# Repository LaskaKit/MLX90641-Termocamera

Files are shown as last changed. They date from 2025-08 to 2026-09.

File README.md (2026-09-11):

# Thermal camera module MLX90641 16×12 px, 55°×35° with μSup connector

A compact thermal camera (thermal imaging) module built around the **Melexis MLX90641** far-infrared array sensor. It gives you **192 real temperature readings (16×12 px)** in every frame, at up to 64 Hz, over I²C - no contact, no extra optics, no calibration needed. Point it at a board, a motor, a radiator, a face or a soldering iron tip and you get the temperature of every point in the scene.

Assembled module

Typical uses: overheating detection on PCBs and in electrical cabinets, presence and people counting, heat-loss inspection, 3D printer and machine monitoring, robotics, or just a DIY thermal camera with a display.

## Why this module and not the bare sensor

The MLX90641 alone is a 4-pin TO-39 can that you have to wire, pull up and power yourself. On this module you get:

- the sensor already soldered on a PCB with the correct decoupling,
- a **[μSup connector](https://blog.laskakit.cz/predstavujeme-univerzalni-konektor-pro-propojeni-modulu-a-cidel-%CE%BCsup/)** - plug it into any LaskaKit board with a single 4-wire cable, no soldering at all,
- solder pads for a standard 2.54 mm 4-pin header (straight or right-angle) if you prefer a breadboard,
- mounting holes so you can actually fix the camera where it should look,
- and **working example code** - Arduino firmware plus a Python live heatmap viewer, see [SW](https://github.com/LaskaKit/MLX90641-Termocamera/tree/main/SW).

## Specification

| | |
|---|---|
| Sensor | Melexis MLX90641 |
| Resolution | 16 × 12 px (192 measuring points) |
| Field of view (FOV) | 55° × 35° |
| Temperature range of the scene | -40 °C to +300 °C |
| Refresh rate | up to 64 Hz (0.5 / 1 / 2 / 4 / 8 / 16 / 32 / 64 Hz) |
| Accuracy | typ. ±1 °C (see the Melexis datasheet) |
| Interface | I²C, up to 1 MHz |
| I²C address | **0x33** |
| Supply voltage | 3.3 V |
| Connectors | μSup (JST-SH 1.0 mm, 4-pin) + pads for a 2.54 mm 4-pin header |
| Module dimensions | 22.9 × 21.6 mm |

Bottom side of the module

## How to connect it

The μSup connector carries **3V3, GND, SDA, SCL**. Connect the module to any of our boards with a single cable - for example the [ESP32-S3 DevKit](https://www.laskakit.cz/laskakit-esp32-s3-devkit/), the [ESP32-DEVKit](https://www.laskakit.cz/laskakit-esp32-devkit/), the low-power [ESP32-C3 LPKit](https://www.laskakit.cz/laskkit-esp-12-board/), [Meteo Mini](https://www.laskakit.cz/laskakit-meteo-mini/) or the [ESPD-3.5 with a 3.5" TFT display](https://www.laskakit.cz/laskakit-espd-35-esp32-3-5-tft-ili9488-touch/), for which we have a **ready-made thermal camera application** - see [ESPD-35/SW/MLX90641-Termocamera](https://github.com/LaskaKit/ESPD-35/tree/main/SW/MLX90641-Termocamera).

You are of course not limited to our boards - any [Arduino](https://www.laskakit.cz/arduino-2/), [Raspberry Pi or Rock Pi](https://www.laskakit.cz/mini-pc/) with a 3.3 V I²C bus will do. Just keep in mind the module is **3.3 V only**, so use a level shifter with 5 V boards.

## Example code

Everything you need is in [SW/mlx90641-test](https://github.com/LaskaKit/MLX90641-Termocamera/tree/main/SW/mlx90641-test):

- `mlx90641-test.ino` - Arduino sketch for ESP32 (tested on LaskaKit ESP32-S3 DevKit: `SDA = GPIO42`, `SCL = GPIO2`, sensor power enable on `GPIO47`). It prints the frame as an **ASCII heatmap**, as a **CSV line with 192 values in °C**, or as a **JSON array** - pick one or more with `USE_ASCII_HEATMAP` / `USE_CSV_OUTPUT` / `USE_JSON_OUTPUT`. Emissivity, refresh rate, frame averaging and image flipping are all at the top of the sketch.
- `MLX90641_API.cpp/.h` - the official [Melexis MLX90641 library](https://github.com/melexis/mlx90641-library).
- `MLX90641_I2C_Driver.cpp/.h` - I²C driver rewritten by us for the Arduino `Wire` library (do **not** use the mbed version).
- `mlx90641_plot.py` - live 16×12 heatmap on your PC over USB serial.
- `mlx90641_plot_640x480.py` - the same, upscaled to 640×480 with interpolation, a marker on the hottest spot and a live temperature readout under the cursor.

Quick start for the Python viewer:

```bash
pip3 install pyserial matplotlib numpy
# optional, for faster and nicer upscaling:
pip3 install opencv-python

# set USE_CSV_OUTPUT 1 in the sketch, set your port in the script, then:
python3 mlx90641_plot.py
```

## What else is in this repository

- `HW/` - schematic in PDF
- `3D/` - 3D model of the module (STEP, Fusion 360)
- `Production/` - gerbers and BOM/CPL files
- `SW/` - example code
### Ready-made thermal camera with a display

If you have the [ESPD-3.5](https://www.laskakit.cz/laskakit-espd-35-esp32-3-5-tft-ili9488-touch/), you don't have to write anything - a complete application that draws the thermal image straight onto the 3.5" touch display lives in the board's repository: [ESPD-35/SW/MLX90641-Termocamera](https://github.com/LaskaKit/ESPD-35/tree/main/SW/MLX90641-Termocamera). Plug the module in with a μSup cable and flash the sketch.
## Where to buy

**[https://www.laskakit.cz/laskakit-mlx90641-modul-termokamery-16--12px-55--x35/](https://www.laskakit.cz/laskakit-mlx90641-modul-termokamery-16--12px-55--x35/)**

Czech version of this readme: [README_CZ.md](README_CZ.md)

Questions? podpora@laskakit.cz

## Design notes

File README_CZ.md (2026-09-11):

# Modul termokamery MLX90641 16×12 px, 55°×35° s konektorem μŠup

Kompaktní modul termokamery postavený na infračerveném maticovém senzoru **Melexis MLX90641**. V každém snímku dostaneš **192 skutečných hodnot teploty (16×12 px)**, až 64× za sekundu, po I²C - bezkontaktně, bez další optiky a bez kalibrace. Namiř ho na desku plošných spojů, motor, radiátor, obličej nebo hrot pájky a máš teplotu každého bodu scény.

Osazený modul

K čemu se hodí: hledání přehřívajících se součástek na DPS a v rozvaděčích, detekce přítomnosti a počítání osob, kontrola tepelných úniků, hlídání 3D tiskárny nebo stroje, robotika - nebo prostě domácí termokamera s displejem.

## Proč modul a ne samotný senzor

Samotný MLX90641 je čtyřvývodové pouzdro TO-39, které si musíš sám zapojit, napájet a doplnit pull-upy. Na tomhle modulu dostaneš:

- senzor už zapájený na desce se správným blokováním napájení,
- **[konektor μŠup](https://blog.laskakit.cz/predstavujeme-univerzalni-konektor-pro-propojeni-modulu-a-cidel-%CE%BCsup/)** - k jakékoli naší desce ho připojíš jedním čtyřžilovým kabelem, bez pájení,
- pájecí plošky pro standardní 4pinový hřebínek s roztečí 2.54 mm (přímý i pravoúhlý), když chceš do nepájivého pole,
- montážní otvory, takže kameru opravdu upevníš tam, kam se má dívat,
- a **funkční ukázkový kód** - firmware pro Arduino a k tomu Python vizualizaci s živou teplotní mapou, viz složka [SW](https://github.com/LaskaKit/MLX90641-Termocamera/tree/main/SW).

## Specifikace

| | |
|---|---|
| Senzor | Melexis MLX90641 |
| Rozlišení | 16 × 12 px (192 měřicích bodů) |
| Zorné pole (FOV) | 55° × 35° |
| Rozsah měřených teplot | -40 °C až +300 °C |
| Obnovovací frekvence | až 64 Hz (0,5 / 1 / 2 / 4 / 8 / 16 / 32 / 64 Hz) |
| Přesnost | typ. ±1 °C (viz katalogový list Melexis) |
| Komunikace | I²C, až 1 MHz |
| I²C adresa | **0x33** |
| Napájecí napětí | 3,3 V |
| Konektory | μŠup (JST-SH 1,0 mm, 4pin) + plošky pro hřebínek 2.54 mm |
| Rozměry modulu | 22,9 × 21,6 mm |

Spodní strana modulu

## Jak ho zapojit

Konektor μŠup vede **3V3, GND, SDA, SCL**. Modul připojíš jedním kabelem k libovolné naší desce - třeba k [ESP32-S3 DevKit](https://www.laskakit.cz/laskakit-esp32-s3-devkit/), [ESP32-DEVKit](https://www.laskakit.cz/laskakit-esp32-devkit/), úspornému [ESP32-C3 LPKit](https://www.laskakit.cz/laskkit-esp-12-board/), [Meteo Mini](https://www.laskakit.cz/laskakit-meteo-mini/) nebo k [ESPD-3.5 s 3,5" TFT displejem](https://www.laskakit.cz/laskakit-espd-35-esp32-3-5-tft-ili9488-touch/), pro který máme **hotovou termokameru s dotykovým displejem** - viz [ESPD-35/SW/MLX90641-Termocamera](https://github.com/LaskaKit/ESPD-35/tree/main/SW/MLX90641-Termocamera).

Naše desky samozřejmě nejsou podmínka - postačí jakékoli [Arduino](https://www.laskakit.cz/arduino-2/), [Raspberry Pi nebo Rock Pi](https://www.laskakit.cz/mini-pc/) s 3,3V I²C sběrnicí. Jen pozor, modul je **pouze na 3,3 V**, takže s pětivoltovými deskami použij převodník úrovní.

## Ukázkový kód

Všechno potřebné najdeš ve složce [SW/mlx90641-test](https://github.com/LaskaKit/MLX90641-Termocamera/tree/main/SW/mlx90641-test):

- `mlx90641-test.ino` - sketch pro ESP32 (testováno na LaskaKit ESP32-S3 DevKit: `SDA = GPIO42`, `SCL = GPIO2`, spínání napájení senzoru na `GPIO47`). Snímek umí vypsat jako **ASCII teplotní mapu**, jako **CSV řádek se 192 hodnotami ve °C** nebo jako **JSON pole** - vybereš přepínači `USE_ASCII_HEATMAP` / `USE_CSV_OUTPUT` / `USE_JSON_OUTPUT`. Emisivitu, obnovovací frekvenci, průměrování snímků i překlopení obrazu nastavíš hned na začátku sketche.
- `MLX90641_API.cpp/.h` - oficiální [knihovna Melexis MLX90641](https://github.com/melexis/mlx90641-library).
- `MLX90641_I2C_Driver.cpp/.h` - I²C driver, který jsme přepsali pro Arduino knihovnu `Wire` (mbed verzi **nepoužívej**).
- `mlx90641_plot.py` - živá teplotní mapa 16×12 na počítači přes USB sériovou linku.
- `mlx90641_plot_640x480.py` - totéž, ale převzorkované na 640×480 s interpolací, značkou na nejteplejším místě a živým odečtem teploty pod kurzorem.

Rychlý start Python vizualizace:

```bash
pip3 install pyserial matplotlib numpy
# volitelně, pro rychlejší a hezčí převzorkování:
pip3 install opencv-python

# ve sketchi nastav USE_CSV_OUTPUT 1, ve skriptu svůj port, a pak:
python3 mlx90641_plot.py
```

## Co dalšího v repozitáři najdeš

- `HW/` - schéma v PDF
- `3D/` - 3D model modulu (STEP, Fusion 360)
- `Production/` - gerbery a soubory BOM/CPL
- `SW/` - ukázkový kód
### Hotová termokamera s displejem

Pokud máš [ESPD-3.5](https://www.laskakit.cz/laskakit-espd-35-esp32-3-5-tft-ili9488-touch/), nemusíš nic psát - kompletní aplikace, která kreslí teplotní obraz přímo na 3,5" dotykový displej, je v repozitáři desky: [ESPD-35/SW/MLX90641-Termocamera](https://github.com/LaskaKit/ESPD-35/tree/main/SW/MLX90641-Termocamera). Modul připojíš kabelem μŠup a nahraješ sketch.
## Kde modul koupíš

**[https://www.laskakit.cz/laskakit-mlx90641-modul-termokamery-16--12px-55--x35/](https://www.laskakit.cz/laskakit-mlx90641-modul-termokamery-16--12px-55--x35/)**

English version: [README.md](README.md)

Dotazy? podpora@laskakit.cz

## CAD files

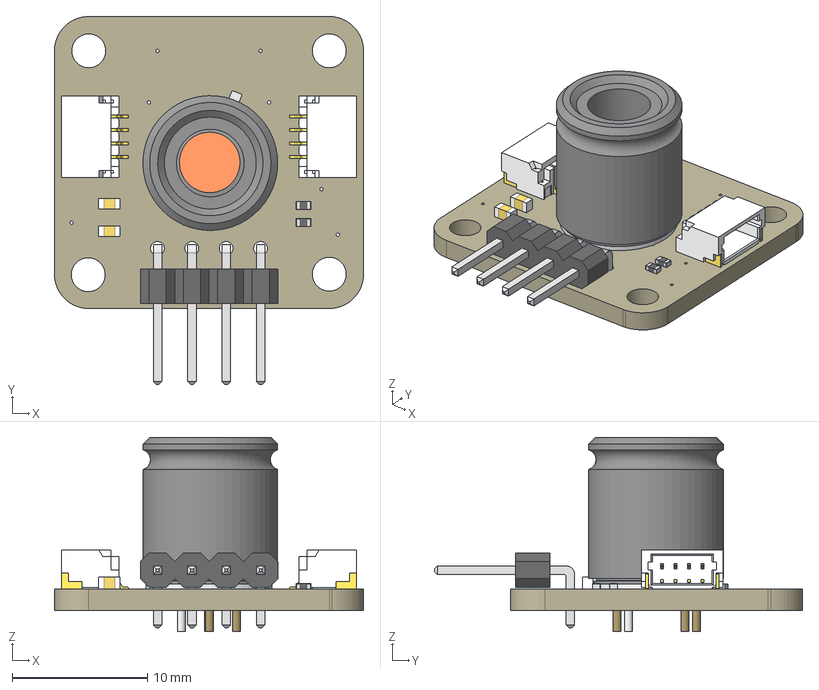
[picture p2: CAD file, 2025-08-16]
3D/MLX90641-Termocamera.step
22.9 x 27.2 x 14.3 mm
Board
LASKAKIT_HEART_4MM
LASKKIT_10MM_SILKSCREEN
USUP_SILKSCREEN x 2
1X04/90
1X04_1MM_RA x 2
2,5-PAD x 4
C0603 x 2
R0402 x 2

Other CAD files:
3D/MLX90641-Termocamera.f3d

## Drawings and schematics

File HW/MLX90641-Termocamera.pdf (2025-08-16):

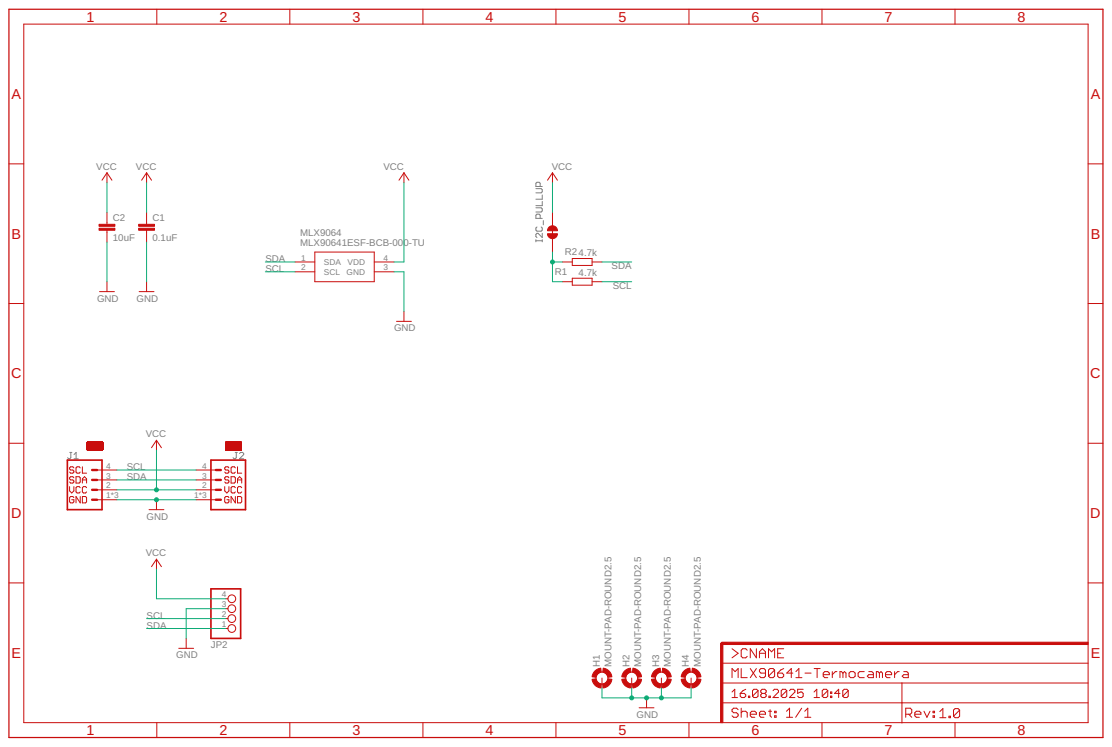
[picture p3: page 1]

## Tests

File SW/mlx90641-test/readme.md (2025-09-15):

# MLX90641 Thermal Camera (LaskaKit ESP32-S3 Devkit + Python Visualization)

This project uses the **LaskaKit MLX90641 (16×12 thermal sensor)** with LaskaKit ESP32-S3 Devkit**.  
The ESP32 reads thermal frames over I²C and streams them as CSV over USB serial.  
A Python script on your PC/Mac listens to the serial data and plots a **live heatmap**.

---

## Hardware Setup
- **LaskaKit ESP32-S3 Dev board** (tested with 16MB Flash variant).
- **MLX90641 sensor** connected via I²C:
  - `SDA → GPIO 42`
  - `SCL → GPIO 2`  
- Power the sensor with **3.3V**.  
  Use `GPIO 47` to turn power ON.

---

## Firmware (ESP32-S3)

1. Clone/download this code into Arduino IDE.
2. Make sure you include:
   - `mlx90641-test.ino` (main sketch)
   - `MLX90641_API.cpp/.h` (from [Melexis MLX90641 library](https://github.com/melexis/mlx90641-library/tree/master/functions))
   - `MLX90641_I2C_Driver.cpp/.h` (Arduino Wire-based driver, not the mbed version!)
3. Upload the sketch to LaskaKit ESP32-S3 Dev board.
4. The firmware will:
    - Initialize the sensor.
    - Set Output:
        - Human-readable **ASCII heatmap** 16x12
        - Output frames as **CSV rows with 192 values** (°C).
        - JSON-like **array** [v0, v1, ..., v191]  
    - You can flif horizontal o vertical
---

## PC Visualization (Python, macOS/Linux/Windows)

### Set Output frames as CSV rows: 
In mlx90641-test.ino:
```bash
#define USE_CSV_OUTPUT    1
```
### Install dependencies
Make sure Python 3 is installed:

```bash
python3 --version
```
If not, install:
```bash
brew install python3
```
Install required packages:
```bash
pip3 install pyserial matplotlib numpy
```
replace port with your in python script:
```bash
PORT = '/dev/tty.wchusbserial5A9B0085741'  # replace with your ESP32 port
```
Run the script:
- 16x12:
```bash
python3 mlx90641_plot.py
```
- 640x480 upscaling + blending:
    - Finds the max temperature in the current (upscaled) frame.
	- Draws a cross at that location and a label with the temperature.
	- Optional: hover the mouse over the image to see live temperature under the cursor.
```bash
python3 mlx90641_plot_640x480.py
```
### Optional OpenCV for fastest, highest-quality resize (INTER_CUBIC/LINEAR):
```bash
pip3 install opencv-python
```

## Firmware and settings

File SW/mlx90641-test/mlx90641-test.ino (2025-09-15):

/* MLX90641 Thermal Camera (LaskaKit ESP32-S3 Devkit + Python Visualization)
 *
 * Board:   LaskaKit ESP32-S3-DEVKit                  https://www.laskakit.cz/laskakit-esp32-s3-devkit
 * Sensor:  LaskaKit MLX90641 Thermocamera 16x12      https://www.laskakit.cz/laskakit-mlx90641-modul-termokamery-16--12px-55--x35/
 *
 * This project uses the **LaskaKit MLX90641 (16×12 thermal sensor)** with LaskaKit ESP32-S3 Devkit**.  
 * The ESP32 reads thermal frames over I²C and streams them as CSV over USB serial.  
 * A Python script on your PC/Mac listens to the serial data and plots a **live heatmap**.
 *
 * Make sure you include (All are prepared in this folder):
 *  - `mlx90641-test.ino` (this sketch)
 *  - `MLX90641_API.cpp/.h` (from [Melexis MLX90641 library: https://github.com/melexis/mlx90641-library/tree/master/)
 *  - `MLX90641_I2C_Driver.cpp/.h` (Arduino Wire-based driver, rewrited by us, ! not the mbed version!)
 *
 * Email:podpora@laskakit.cz
 * Web:laskakit.cz
 */


#define POWER_PIN 47
#define I2C_SDA   42
#define I2C_SCL    2

#include <Arduino.h>
#include <Wire.h>
#include "MLX90641_API.h"
#include "MLX90641_I2C_Driver.h"

// ----------------------- User configuration -----------------------
// Emissivity (paper ~0.95, skin ~0.98, matte plastics ~0.95, shiny metals << 0.95)
static const float EMISSIVITY = 0.95f;

// MLX90641 refresh (0x03=8Hz, 0x04=16Hz, 0x05=32Hz, 0x06=64Hz)
// Start at 8 or 16 Hz while testing. Higher rates need clean wiring.
static const uint8_t MLX_REFRESH = 0x04; // 16 Hz

// I2C speeds: start slower for reliable init; speed up after success.
static const uint32_t I2C_SPEED_INIT_HZ = 100000;  // 100 kHz during init
static const uint32_t I2C_SPEED_RUN_HZ  = 400000;  // 400 kHz after init

// Output modes (set exactly one of them to 1 if you prefer a single format)
// You can enable multiple; they will print in this order each frame.
#define USE_ASCII_HEATMAP 1   // Human-readable ASCII heatmap 16x12
#define USE_CSV_OUTPUT    0   // One CSV line with 192 values (°C with 2 decimals)
#define USE_JSON_OUTPUT   0   // JSON-like array [v0, v1, ..., v191]

// Optional frame averaging to reduce noise. 0 disables averaging.
#define AVERAGE_N         4   // Average N consecutive frames (e.g., 4). Set 0 to disable.

// Optional image orientation fixes
#define FLIP_VERTICAL     0   // 1 to flip top/bottom
#define FLIP_HORIZONTAL   0   // 1 to flip left/right

// Optional I2C scan at boot (handy for debugging)
#define RUN_I2C_SCAN      0

// ------------------------------------------------------------------

static const uint8_t MLX_ADDR = 0x33;    // Default 7-bit I2C address
paramsMLX90641 gParams;                  // Parameter struct for MLX90641
uint16_t gEE[832];                       // EEPROM dump (832 words)
uint16_t gFrame[242];                    // Raw frame (242 words)
float    gTo[16 * 12];                   // Temperatures (°C), 192 values

#if AVERAGE_N > 0
static float gAcc[16 * 12];              // Accumulator for averaging
static int   gAccCount = 0;
#endif

// ----------------------- Helpers -----------------------
static void i2cScan() {
  Serial.println("I2C scan:");
  uint8_t found = 0;
  for (uint8_t a = 1; a < 127; ++a) {
    Wire.beginTransmission(a);
    if (Wire.endTransmission() == 0) {
      Serial.printf("  found 0x%02X\n", a);
      ++found;
    }
  }
  Serial.printf("Found %u device(s)\n", found);
}

static void flipIfNeeded(float* img, int w, int h) {
#if FLIP_VERTICAL
  for (int r = 0; r < h / 2; ++r) {
    for (int c = 0; c < w; ++c) {
      float tmp = img[r * w + c];
      img[r * w + c] = img[(h - 1 - r) * w + c];
      img[(h - 1 - r) * w + c] = tmp;
    }
  }
#endif
#if FLIP_HORIZONTAL
  for (int r = 0; r < h; ++r) {
    for (int c = 0; c < w / 2; ++c) {
      float tmp = img[r * w + c];
      img[r * w + c] = img[r * w + (w - 1 - c)];
      img[r * w + (w - 1 - c)] = tmp;
    }
  }
#endif
}

static void printStats(const float* img, int count) {
  float tMin = 1e9f, tMax = -1e9f, sum = 0.f;
  for (int i = 0; i < count; ++i) {
    float v = img[i];
    if (v < tMin) tMin = v;
    if (v > tMax) tMax = v;
    sum += v;
  }
  float avg = sum / count;
  Serial.printf("MLX90641 16x12  min=%.2f°C  max=%.2f°C  avg=%.2f°C\n", tMin, tMax, avg);
}

#if USE_ASCII_HEATMAP
static void printAsciiHeatmap(const float* img, int w, int h) {
  // Compute min/max for mapping to ASCII ramp
  float tMin =  1e9f, tMax = -1e9f;
  for (int i = 0; i < w*h; ++i) { 
    if (img[i] < tMin) tMin = img[i];
    if (img[i] > tMax) tMax = img[i];
  }
  const char* ramp = " .:-=+*#%@"; // 10 levels
  float range = max(0.1f, tMax - tMin);

  for (int r = 0; r < h; ++r) {
    for (int c = 0; c < w; ++c) {
      float t = img[r * w + c];
      int level = (int)((t - tMin) / range * 9.0f + 0.5f);
      level = constrain(level, 0, 9);
      Serial.print(ramp[level]);
    }
    Serial.println();
  }
}
#endif

#if USE_CSV_OUTPUT
static void printCSV(const float* img, int count) {
  // Single CSV line with count values (two decimals)
  for (int i = 0; i < count; ++i) {
    Serial.print(img[i], 2);
    if (i < count - 1) Serial.print(',');
  }
  Serial.println();
}
#endif

#if USE_JSON_OUTPUT
static void printJSON(const float* img, int count) {
  Serial.print('[');
  for (int i = 0; i < count; ++i) {
    if (i) Serial.print(',');
    Serial.print(img[i], 2);
  }
  Serial.println(']');
}
#endif

// ----------------------- Setup/Loop -----------------------
void setup() {
  pinMode(POWER_PIN, OUTPUT);
  digitalWrite(POWER_PIN, HIGH);       // For production, consider powering MLX from 3V3 rail.
  delay(400);                          // Give sensor time after power-up

  Serial.begin(115200);
  unsigned long t0 = millis();
  while (!Serial && (millis() - t0 < 2000)) { delay(10); } // Don't block forever

  // Start I2C slow and with a reasonable timeout for DumpEE
  Wire.begin(I2C_SDA, I2C_SCL, I2C_SPEED_INIT_HZ);
  Wire.setTimeOut(500);

#if RUN_I2C_SCAN
  i2cScan(); // Expect to see 0x33
#endif

  // --- Robust initialization sequence ---
  const int MAX_RETRY = 5;
  int st = -1;

  // Dump EEPROM (832 words). Our I2CRead() reads in chunks to avoid Wire RX buffer overflow.
  for (int i = 0; i < MAX_RETRY; ++i) {
    delay(60);
    st = MLX90641_DumpEE(MLX_ADDR, gEE);
    if (st == 0) break;
    Serial.printf("DumpEE try %d failed: %d\n", i + 1, st);
  }
  if (st != 0) {
    Serial.printf("DumpEE final fail: %d\n", st);
    while (1) delay(10);
  }

  // Extract calibration parameters for MLX90641
  st = MLX90641_ExtractParameters(gEE, &gParams);
  if (st != 0) {
    Serial.printf("ExtractParameters fail: %d\n", st);
    while (1) delay(10);
  }

  // Set refresh (MLX90641 has no Chess/Interleaved mode switch)
  MLX90641_SetRefreshRate(MLX_ADDR, MLX_REFRESH);

  // Optional: read Control Register 1 (0x800D) for info/debug
  uint16_t ctrl1 = 0;
  if (MLX90641_I2CRead(MLX_ADDR, 0x800D, 1, &ctrl1) == 0) {
    Serial.printf("CTRL1=0x%04X\n", ctrl1);
  }

  // After successful init: speed up I2C for frame reads
  Wire.setClock(I2C_SPEED_RUN_HZ);
  Serial.println("Init OK.");
}

void loop() {
  // Grab one raw frame (242 words)
  int st = MLX90641_GetFrameData(MLX_ADDR, gFrame);
  if (st < 0) {
    Serial.printf("GetFrameData error=%d\n", st);
    delay(60);
    return;
  }

  // Compute ambient temperature (Ta) and then per-pixel object temps (To, °C)
  float Ta = MLX90641_GetTa(gFrame, &gParams);
  MLX90641_CalculateTo(gFrame, &gParams, EMISSIVITY, Ta, gTo);

  // Optional image orientation fixes
  flipIfNeeded(gTo, 16, 12);

#if AVERAGE_N > 0
  // Simple running average over AVERAGE_N frames to reduce noise
  for (int i = 0; i < 16 * 12; ++i) {
    // Running average: acc = (acc*n + new)/(n+1)
    gAcc[i] = (gAcc[i] * gAccCount + gTo[i]) / (gAccCount + 1);
  }
  gAccCount++;

  if (gAccCount >= AVERAGE_N) {
    printStats(gAcc, 16 * 12);

  #if USE_ASCII_HEATMAP
    printAsciiHeatmap(gAcc, 16, 12);
  #endif
  #if USE_CSV_OUTPUT
    printCSV(gAcc, 16 * 12);
  #endif
  #if USE_JSON_OUTPUT
    printJSON(gAcc, 16 * 12);
  #endif

    // Reset accumulator
    memset(gAcc, 0, sizeof(gAcc));
    gAccCount = 0;
  }
#else
  // No averaging: print current frame directly
  printStats(gTo, 16 * 12);

#if USE_ASCII_HEATMAP
  printAsciiHeatmap(gTo, 16, 12);
#endif
#if USE_CSV_OUTPUT
  printCSV(gTo, 16 * 12);
#endif
#if USE_JSON_OUTPUT
  printJSON(gTo, 16 * 12);
#endif

#endif // AVERAGE_N

  // Delay according to refresh. For 16 Hz, ~62.5 ms; we keep ~150 ms to be gentle.
  delay(150);
}

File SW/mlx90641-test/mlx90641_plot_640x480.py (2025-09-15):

#!/usr/bin/env python3
"""
Live MLX90641 viewer (CSV over serial) with 640x480 upscaling + blending
and an overlay crosshair + temperature label on the hottest pixel.
Also shows a hover readout for temperature under the mouse.

- Reads 192 floats per line from serial (16x12).
- Upscales to 640x480 (OpenCV if available, else pure-NumPy bilinear).
- Auto-scales color limits with EMA smoothing to reduce flicker.
- Press 's' to save a PNG of the current view.
"""

import sys
import time
import numpy as np
import matplotlib.pyplot as plt

# --- Try OpenCV; fall back to pure NumPy if unavailable ---
try:
    import cv2
    HAS_CV2 = True
except Exception:
    HAS_CV2 = False

# ------------------------- CONFIG -------------------------
PORT = '/dev/tty.wchusbserial5A9B0085741'  # <- set your port (macOS: ls /dev/tty.*)
BAUD = 115200

SRC_W, SRC_H = 16, 12             # MLX90641 native resolution
OUT_W, OUT_H = 640, 480           # Target upscaled resolution

CLIM_SMOOTH = 0.2                 # 0..1, EMA for vmin/vmax
CMAP = 'inferno'                  # matplotlib colormap
CV2_INTERP = 'cubic'              # 'linear' or 'cubic' (if OpenCV present)

PLOT_DT = 0.001                   # Throttle UI updates (seconds)

CROSS_SIZE = 18                   # half-length of crosshair in output pixels
CROSS_LINEWIDTH = 1.5
LABEL_FMT = "{:.2f} °C"

HOVER_READOUT = True              # show temp under mouse cursor

# ----------------------- SERIAL SETUP ----------------------
import serial
def open_serial(port: str, baud: int, timeout: float = 1.0) -> serial.Serial:
    return serial.Serial(port, baud, timeout=timeout)

# -------------------- UPSCALING (BLENDING) ----------------
def upscale_np_bilinear(src: np.ndarray, out_w: int, out_h: int) -> np.ndarray:
    """Pure-NumPy bilinear upscaling: horizontal pass then vertical pass."""
    h, w = src.shape
    x_src = np.arange(w, dtype=np.float32)
    x_dst = np.linspace(0, w - 1, out_w, dtype=np.float32)
    tmp = np.empty((h, out_w), dtype=np.float32)
    for r in range(h):
        tmp[r, :] = np.interp(x_dst, x_src, src[r, :])
    y_src = np.arange(h, dtype=np.float32)
    y_dst = np.linspace(0, h - 1, out_h, dtype=np.float32)
    out = np.empty((out_h, out_w), dtype=np.float32)
    for c in range(out_w):
        out[:, c] = np.interp(y_dst, y_src, tmp[:, c])
    return out

def upscale(frame_12x16: np.ndarray) -> np.ndarray:
    if HAS_CV2:
        inter = cv2.INTER_CUBIC if CV2_INTERP.lower().startswith('c') else cv2.INTER_LINEAR
        f32 = np.ascontiguousarray(frame_12x16, dtype=np.float32)
        return cv2.resize(f32, (OUT_W, OUT_H), interpolation=inter)
    else:
        return upscale_np_bilinear(frame_12x16.astype(np.float32), OUT_W, OUT_H)

# ----------------------- PLOTTING -------------------------
plt.ion()
fig, ax = plt.subplots(figsize=(8, 6))
img = ax.imshow(np.zeros((OUT_H, OUT_W), dtype=np.float32),
                vmin=20, vmax=35, cmap=CMAP, origin='lower', aspect='equal')
cbar = plt.colorbar(img, ax=ax)
ax.set_title('MLX90641 (16×12 → 640×480)')
ax.set_xlabel('X')
ax.set_ylabel('Y')

# Crosshair lines (two Line2D objects) + label (Text)
cross_h, = ax.plot([], [], '-', linewidth=CROSS_LINEWIDTH)
cross_v, = ax.plot([], [], '-', linewidth=CROSS_LINEWIDTH)
label = ax.text(0, 0, "", color='white', fontsize=10,
                ha='left', va='bottom',
                bbox=dict(facecolor='black', alpha=0.6, boxstyle='round,pad=0.3'))

# Set crosshair color based on the colormap's brightest color
try:
    # Use the last color from the colormap for visibility
    cross_color = plt.get_cmap(CMAP)(1.0)
except Exception:
    cross_color = (1, 1, 1, 1)
cross_h.set_color(cross_color)
cross_v.set_color(cross_color)

vmin_ema = 20.0
vmax_ema = 35.0

def update_clim_auto(frame: np.ndarray):
    """Exponential moving average for color limits to reduce flicker."""
    global vmin_ema, vmax_ema
    fmin = float(np.min(frame))
    fmax = float(np.max(frame))
    # Expand tiny ranges to avoid flat images
    if fmax - fmin < 0.5:
        pad = 0.25
        fmin -= pad
        fmax += pad
    # EMA
    alpha = CLIM_SMOOTH
    vmin_ema = (1 - alpha) * vmin_ema + alpha * fmin
    vmax_ema = (1 - alpha) * vmax_ema + alpha * fmax
    # Ensure minimum span
    if vmax_ema - vmin_ema < 0.5:
        mid = 0.5 * (vmin_ema + vmax_ema)
        vmin_ema = mid - 0.25
        vmax_ema = mid + 0.25
    img.set_clim(vmin=vmin_ema, vmax=vmax_ema)
    cbar.update_normal(img)

def draw_cross_with_label(frame_up: np.ndarray):
    """Draw crosshair + label at the hottest pixel in the upscaled frame."""
    # Locate hottest pixel
    idx = np.argmax(frame_up)
    y, x = divmod(int(idx), frame_up.shape[1])
    t = float(frame_up[y, x])

    # Crosshair geometry (clamped to image bounds)
    x0 = max(0, x - CROSS_SIZE)
    x1 = min(OUT_W - 1, x + CROSS_SIZE)
    y0 = max(0, y - CROSS_SIZE)
    y1 = min(OUT_H - 1, y + CROSS_SIZE)

    # Update line data
    cross_h.set_data([x0, x1], [y, y])
    cross_v.set_data([x, x], [y0, y1])

    # Update label slightly offset to avoid covering the cross center
    label.set_position((x + 6, y + 6))
    label.set_text(LABEL_FMT.format(t))

# Optional: show temp under mouse cursor
hover_text = ax.text(0.98, 0.02, "", color='white', fontsize=9,
                     ha='right', va='bottom', transform=ax.transAxes,
                     bbox=dict(facecolor='black', alpha=0.4, boxstyle='round,pad=0.3')) if HOVER_READOUT else None

def on_move(event):
    if not HOVER_READOUT or not event.inaxes or img.get_array() is None:
        return
    # Data coordinates align with pixel indices because aspect='equal' and origin='lower'
    x, y = int(round(event.xdata)), int(round(event.ydata))
    arr = img.get_array()
    if 0 <= x < arr.shape[1] and 0 <= y < arr.shape[0]:
        temp = float(arr[y, x])
        hover_text.set_text(f"{temp:.2f} °C  @ ({x},{y})")
        fig.canvas.draw_idle()
fig.canvas.mpl_connect('motion_notify_event', on_move)
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
